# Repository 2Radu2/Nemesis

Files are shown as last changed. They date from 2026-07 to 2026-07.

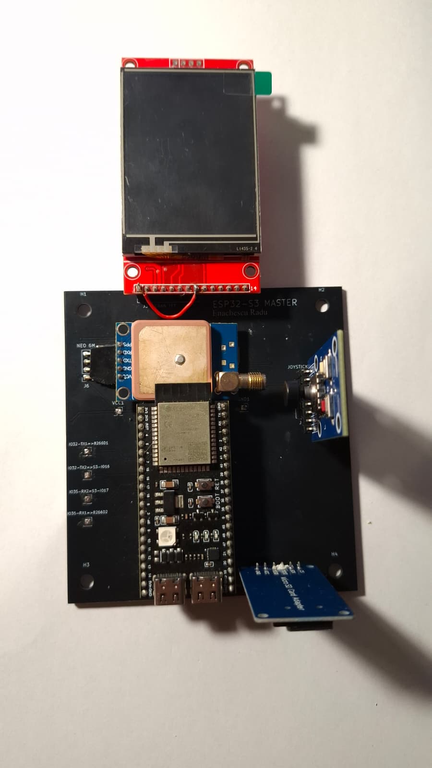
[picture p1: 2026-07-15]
Images/PCB populated & unpopulated/esp32 master pop.jpeg

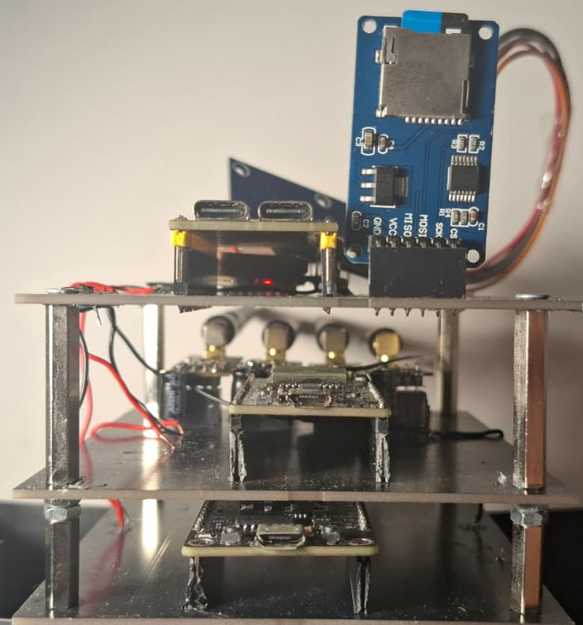
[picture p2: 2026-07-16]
Images/Final Stack/back view.jpeg

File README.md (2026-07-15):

# Project Nemesis: Modular Wireless Auditor

## Legal Disclaimer
**This project is for educational and academic research purposes only.**

Project Nemesis was developed as a university thesis project to audit, stress-test, and evaluate the resilience of modern wireless protocols (IEEE 802.11 and Bluetooth) in strictly controlled and isolated laboratory environments.

The author does not endorse, encourage, or take responsibility for any illegal, malicious, or unauthorized use of this hardware or software. Transmitting jamming signals or executing deauthentication attacks against networks or devices without explicit, written permission from the network owner is a federal crime in many jurisdictions (including under FCC regulations in the United States and similar laws worldwide).

By downloading, viewing, or building this project, you agree that you are solely responsible for your own actions and that you will comply with all local, state, and federal laws.

---

##  Overview
Project Nemesis is a portable, offensive security embedded system designed to audit and stress-test the resilience of modern wireless networks (Wi-Fi & Bluetooth).

Unlike standard auditing tools that rely on a single microcontroller (which often leads to severe UI lag and firmware bottlenecks during heavy RF injection), this project utilizes a custom **3-Stack Hardware Architecture**:
- **Layer 1 (Master Controller):** An ESP32-S3 handling the TFT UI, joystick navigation, and SD-Card GPS logging, completely isolated from RF tasks to ensure zero UI lag.
- **Layer 2 (Bluetooth Disruption):** An ESP32-32U paired with a Quad-nRF24L01+PA+LNA array. It executes protocol-level BLE advertising floods and brute-force AFH (Adaptive Frequency Hopping) poisoning across 79 channels.
- **Layer 3 (Wi-Fi Attacker):** An ESP8266 utilizing the raw Espressif SDK to execute 802.11 deauthentication and beacon spam attacks.

By synchronizing these independent layers, the system can execute "Combo Max"—a simultaneous, multi-vector attack capable of completely saturating the 2.4 GHz spectrum while maintaining a perfectly fluid user interface.

##  Hardware Components
This project relies on a custom 3-stack PCB architecture to distribute processing power and prevent UI bottlenecks. Below is the full bill of materials (BOM):

### Layer 1: Master Controller & UI
*   **Microcontroller:** ESP32-S3 (Dev Module)
*   **Display:** SPI TFT LCD Screen (e.g., ILI9341)
*   **Input:** 5-Pin Analog/Digital Joystick Module
*   **Telemetry:** GPS Module (u-blox NEO-6M / 7M)
*   **Storage:** MicroSD Card Adapter (SPI) + MicroSD Card

### Layer 2: Bluetooth Jammer
*   **Microcontroller:** ESP32-WROOM-32U (with U.FL connector for external BLE antenna)
*   **RF Array:** 4x nRF24L01+PA+LNA Transceiver Modules
*   **Antennas:** 5x 2.4GHz SMA Antennas (4 for NRF modules, 1 for ESP32 BLE)
*   **Power Smoothing:** 4x 10µF - 100µF Capacitors (essential for NRF module power stability)

### Layer 3: Wi-Fi Attacker
*   **Microcontroller:** ESP8266 (NodeMCU / Wemos D1 Mini)

### Power Delivery & PCB
*   **Battery:** 2500mAh Li-Po Battery (must support high current discharge ~1A+)
*   **Power Regulation:** High-current 3.3V and 5V Voltage Regulators
*   **Custom PCBs:** 3x Custom-designed Gerber boards (included in the /Hardware folder)

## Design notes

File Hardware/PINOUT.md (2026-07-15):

# Nemesis Hardware Pinout & Wiring Guide

This document provides the final, corrected pin mappings for the 3-stack PCB architecture, exactly as defined in the official thesis documentation. Use this as the definitive guide when wiring breadboards or soldering the PCBs.

---

## 1. ESP32-S3 (Master Controller)
*The central orchestrator and UI hub.*

### TFT LCD Display (SPI)
| Pin | ESP32-S3 GPIO |
| :--- | :--- |
| **MOSI** | `GPIO 11` |
| **SCK** | `GPIO 12` |
| **CS** | `GPIO 10` |
| **RST** | `GPIO 21` |
| **DC** | `GPIO 14` |
| **BL** (Backlight) | `GPIO 15` |

### MicroSD Card Adapter (SPI)
| Pin | ESP32-S3 GPIO |
| :--- | :--- |
| **MOSI** | `GPIO 39` |
| **MISO** | `GPIO 40` |
| **SCK** | `GPIO 38` |
| **CS** | `GPIO 41` |

### Peripheral Inputs
| Component | ESP32-S3 GPIO |
| :--- | :--- |
| **GPS Module (NEO-6M) RX** | `GPIO 18` |
| **Joystick UP** | `GPIO 1` |
| **Joystick DOWN** | `GPIO 2` |
| **Joystick LEFT** | `GPIO 4` |
| **Joystick RIGHT** | `GPIO 5` |
| **Joystick CENTER** | `GPIO 6` |

### Serial Comms to Slaves (UART)
| Slave | S3 TX Pin | S3 RX Pin |
| :--- | :--- | :--- |
| **To ESP32-32U (Bluetooth)** | `GPIO 17` | `GPIO 16` |
| **To ESP8266 (Wi-Fi)** | `GPIO 7` | `GPIO 8` |

---

## 2. ESP32-WROOM-32U (Bluetooth Jammer)
*The dedicated slave handling the quad-nRF array and BLE floods.*

### Serial Comms to Master
| Pin | ESP32-32U GPIO | Connects To |
| :--- | :--- | :--- |
| **RX** | `GPIO 35` | S3 TX (`GPIO 17`) |
| **TX** | `GPIO 32` | S3 RX (`GPIO 16`) |

### Shared SPI Buses for NRF Modules
To prevent data collisions during high-speed AFH poisoning, the 4 radios are split across two separate hardware SPI buses.

| Bus | Radios | MOSI | MISO | SCK |
| :--- | :--- | :--- | :--- | :--- |
| **HSPI** | NRF 1 & 2 | `13` | `12` | `14` |
| **VSPI** | NRF 3 & 4 | `23` | `19` | `18` |

### NRF Individual Control Pins (CE & CSN)
| Module | CE Pin | CSN Pin |
| :--- | :--- | :--- |
| **NRF 1** | `GPIO 16` | `GPIO 15` |
| **NRF 2** | `GPIO 17` | `GPIO 4` |
| **NRF 3** | `GPIO 25` | `GPIO 26` |
| **NRF 4** | `GPIO 22` | `GPIO 21` |

---

## 3. ESP8266 (Wi-Fi Attacker)
*The dedicated Wi-Fi Deauthentication and Beacon Flood coprocessor.*

### Serial Comms to Master
| Pin | ESP8266 Pin | Connects To |
| :--- | :--- | :--- |
| **RX** | `D1 (GPIO 5)` | S3 TX (`GPIO 7`) |
| **TX** | `D2 (GPIO 4)` | S3 RX (`GPIO 8`) |

> [!IMPORTANT]
> **UART Crossover Rule:** When connecting the master to the slaves, you must cross the lines. The **TX** on the Master goes to the **RX** on the slave, and vice-versa.

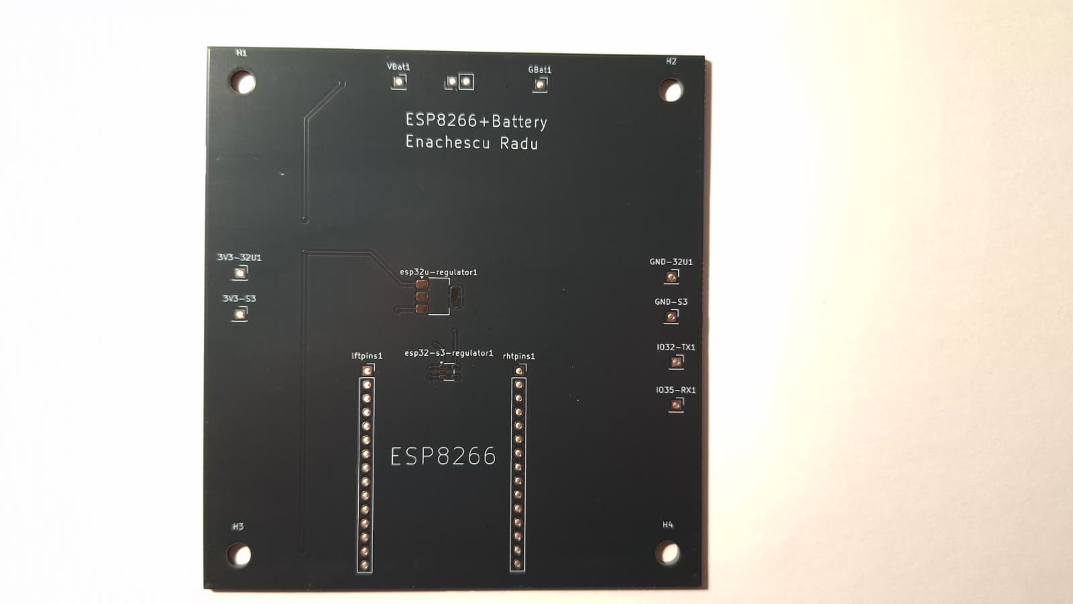
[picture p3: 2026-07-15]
Images/PCB populated & unpopulated/esp8266 unpop.jpeg

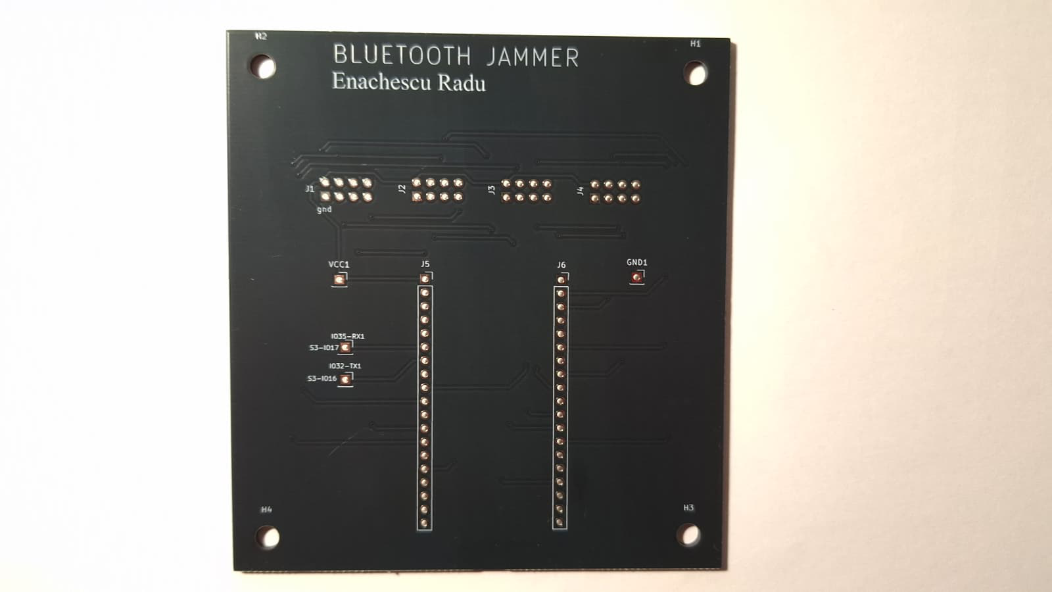
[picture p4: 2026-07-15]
Images/PCB populated & unpopulated/bt jammer unpop.jpeg

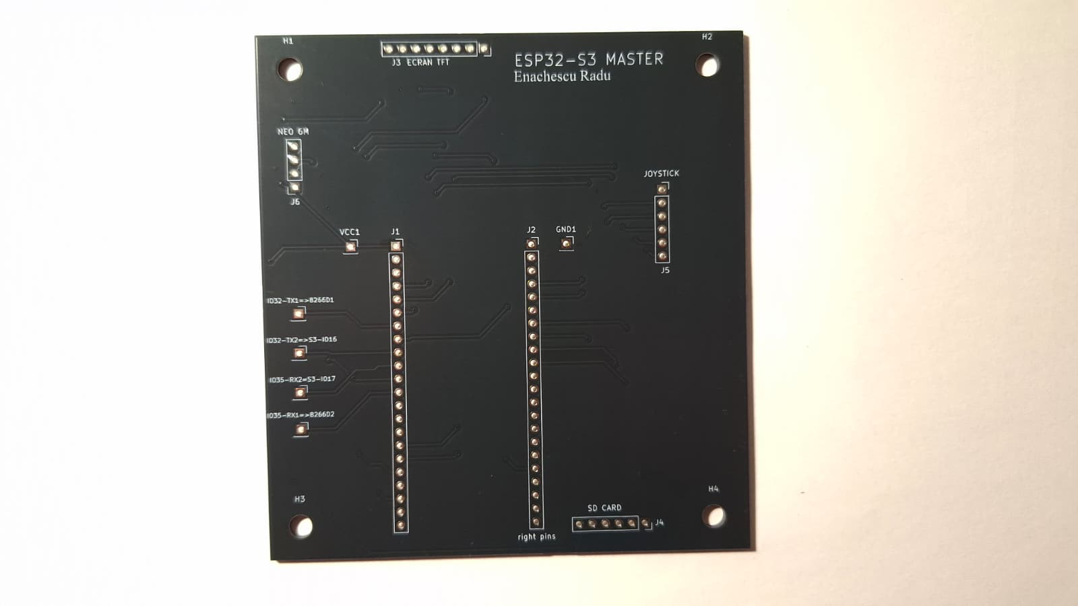
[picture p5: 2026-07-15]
Images/PCB populated & unpopulated/esp32 master unpop.jpeg

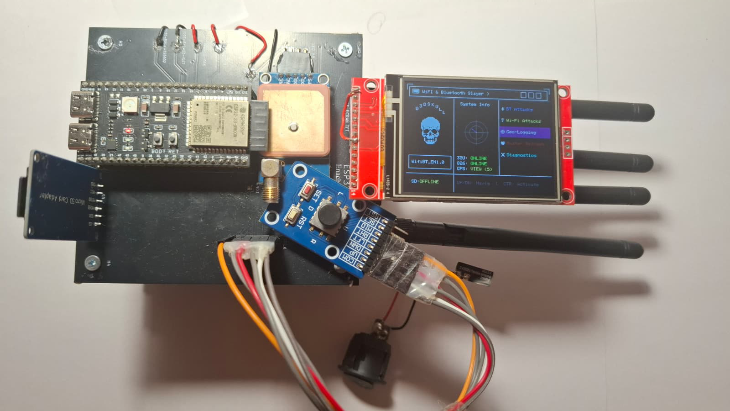
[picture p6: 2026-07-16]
Images/Final Stack/top view.jpeg

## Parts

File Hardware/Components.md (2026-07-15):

##  Hardware Components

This project relies on a custom 3-stack PCB architecture to distribute processing power and prevent UI bottlenecks. Below is the full bill of materials (BOM):

### Layer 1: Master Controller & UI
*   **Microcontroller:** ESP32-S3 (Dev Module)
*   **Display:** SPI TFT LCD Screen (e.g., ILI9341)
*   **Input:** 5-Pin Analog/Digital Joystick Module
*   **Telemetry:** GPS Module (u-blox NEO-6M / 7M)
*   **Storage:** MicroSD Card Adapter (SPI) + MicroSD Card

### Layer 2: Bluetooth Jammer
*   **Microcontroller:** ESP32-WROOM-32U (with U.FL connector for external BLE antenna)
*   **RF Array:** 4x nRF24L01+PA+LNA Transceiver Modules
*   **Antennas:** 4x 2.4GHz SMA Antennas + 1x 2.4Ghz U.FL (4 for NRF modules, 1 for ESP32 BLE)
*   **Power Smoothing:** 4x 10µF - 100µF Capacitors (essential for NRF module power stability, connected on the VCC& GND of the nRF24L01)

### Layer 3: Wi-Fi Attacker
*   **Microcontroller:** ESP8266 (NodeMCU / Wemos D1 Mini)

### Power Delivery & PCB
*   **Battery:** 2500mAh Li-Po Battery (must support high current discharge ~1A+)
*   **Power Regulation:** High-current 3.3V and 5V Voltage Regulators (LDOs/Buck converters capable of handling >1A peaks)
*   **Custom PCBs:** 3x Custom-designed Gerber boards (included in the `/Hardware` folder)
*   **Connectors:** 2.54mm Pitch Male/Female Headers for stacking

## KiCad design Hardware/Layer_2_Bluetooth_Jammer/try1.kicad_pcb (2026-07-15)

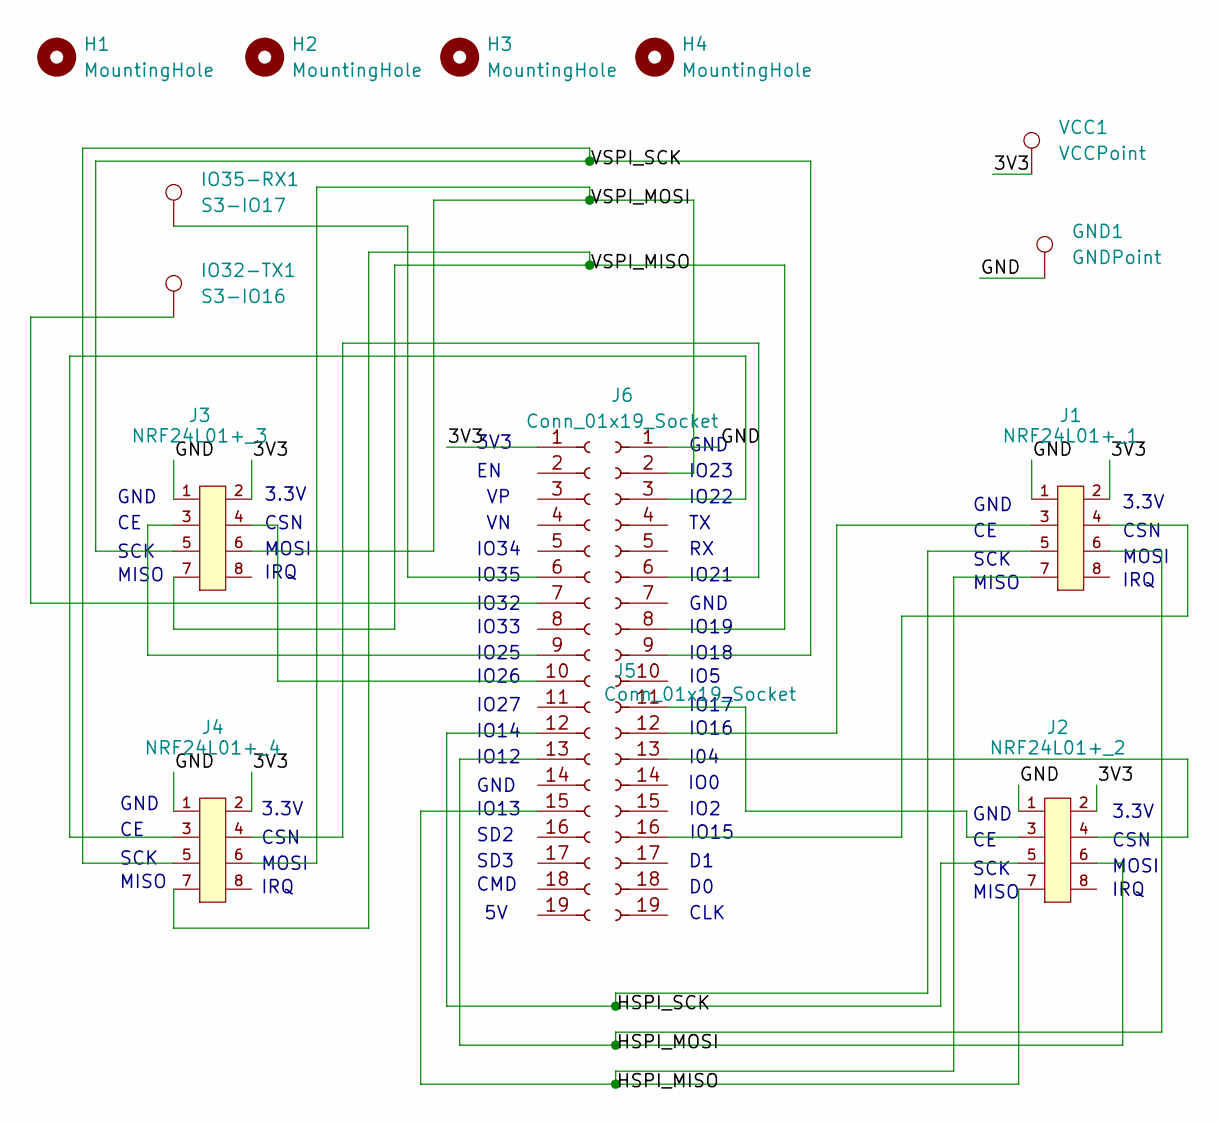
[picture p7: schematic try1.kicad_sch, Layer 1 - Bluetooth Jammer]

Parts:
GND1: GNDPoint; PinSocket_1x01_P2.54mm_Vertical
H1, H2, H3, H4: MountingHole; MountingHole_4.3mm_M4
IO32-TX1: S3-IO16; PinSocket_1x01_P2.54mm_Vertical
IO35-RX1: S3-IO17; PinSocket_1x01_P2.54mm_Vertical
J1: NRF24L01+_1; PinSocket_2x04_P2.54mm_Vertical
J2: NRF24L01+_2; PinSocket_2x04_P2.54mm_Vertical
J3: NRF24L01+_3; PinSocket_2x04_P2.54mm_Vertical
J4: NRF24L01+_4; PinSocket_2x04_P2.54mm_Vertical
J5, J6: Conn_01x19_Socket; PinSocket_1x19_P2.54mm_Vertical
VCC1: VCCPoint; PinSocket_1x01_P2.54mm_Vertical

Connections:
/3V3: J1.2 (VCC), J2.2 (VCC), J3.2 (VCC), J4.2 (VCC), J5.1, VCC1.1 (1_1)
/GND: GND1.1 (1_1), J1.1 (GND), J2.1 (GND), J3.1 (GND), J4.1 (GND), J6.1
/HSPI_MISO: J1.7 (MISO), J2.7 (MISO), J5.15
/HSPI_MOSI: J1.6 (MOSI), J2.6 (MOSI), J5.13
/HSPI_SCK: J1.5 (SCK), J2.5 (SCK), J5.12
/VSPI_MISO: J3.7 (MISO), J4.7 (MISO), J6.8
/VSPI_MOSI: J3.6 (MOSI), J4.6 (MOSI), J6.2
/VSPI_SCK: J3.5 (SCK), J4.5 (SCK), J6.9
unnamed: J1.3 (CE), J6.12
unnamed: J1.4 (CSN), J6.16
unnamed: J2.3 (CE), J6.11
unnamed: J2.4 (CSN), J6.13
unnamed: J3.3 (CE), J5.9
unnamed: J3.4 (CSN), J5.10
unnamed: J4.3 (CE), J6.3
unnamed: J4.4 (CSN), J6.6
unnamed: IO35-RX1.1 (1_1), J5.6
unnamed: IO32-TX1.1 (1_1), J5.7

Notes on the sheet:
MOSI
IO21
IO27
SCK
IO19
3.3V
IO14
SD3
I04
IO17
GND
IO2
3V3
IO23
IO16
CSN
MISO
GND
IO0
CLK
CMD
IO18
IO32
IO5
IO15
IO34
IO12
IO13
IRQ
IO35
IO33
IO26
IO22
IO25
SD2

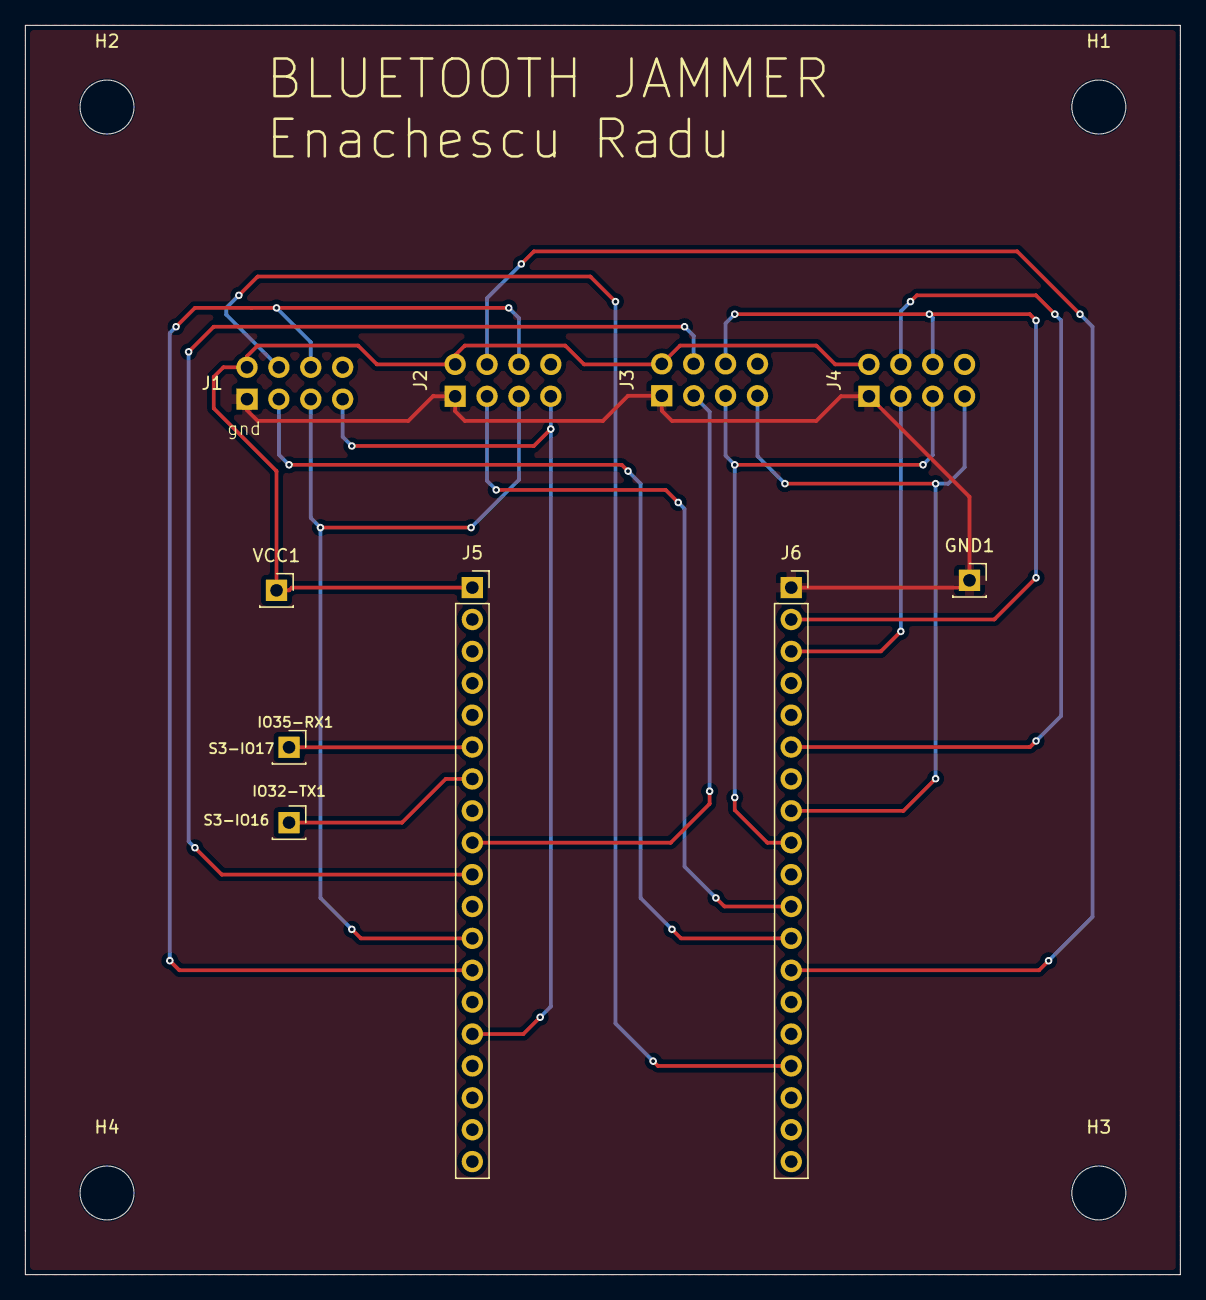
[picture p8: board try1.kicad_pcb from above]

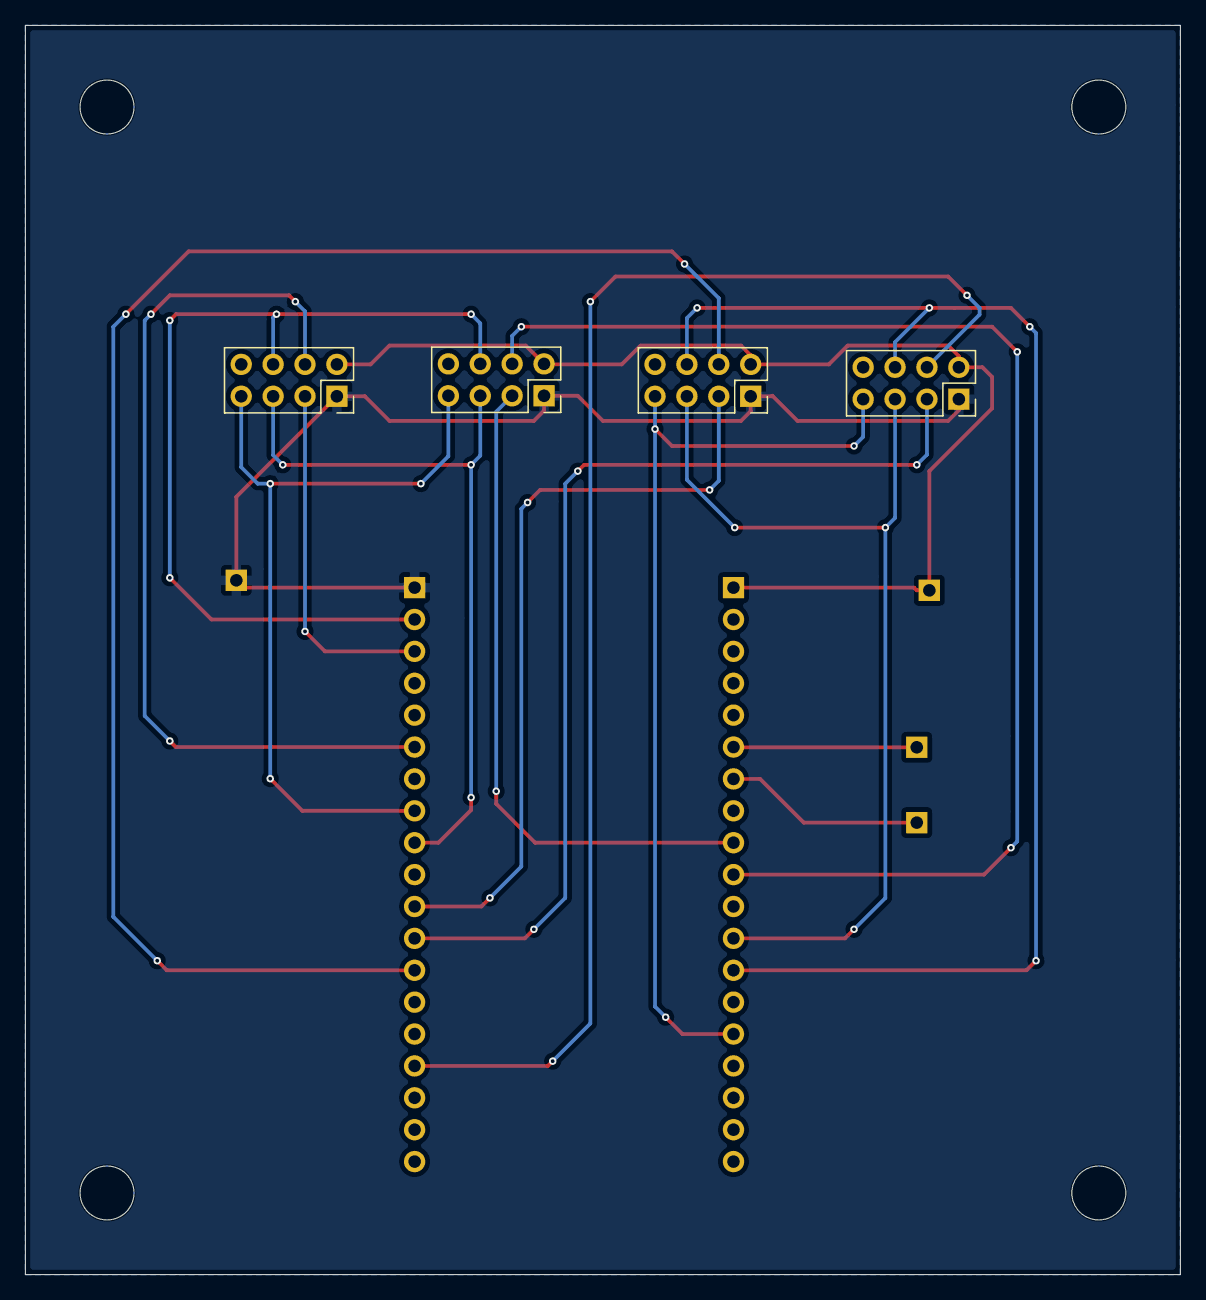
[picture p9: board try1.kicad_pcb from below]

Board: 2 copper layers, 92.0 x 99.5 mm, 14 parts (4 on the bottom side), 18 nets.

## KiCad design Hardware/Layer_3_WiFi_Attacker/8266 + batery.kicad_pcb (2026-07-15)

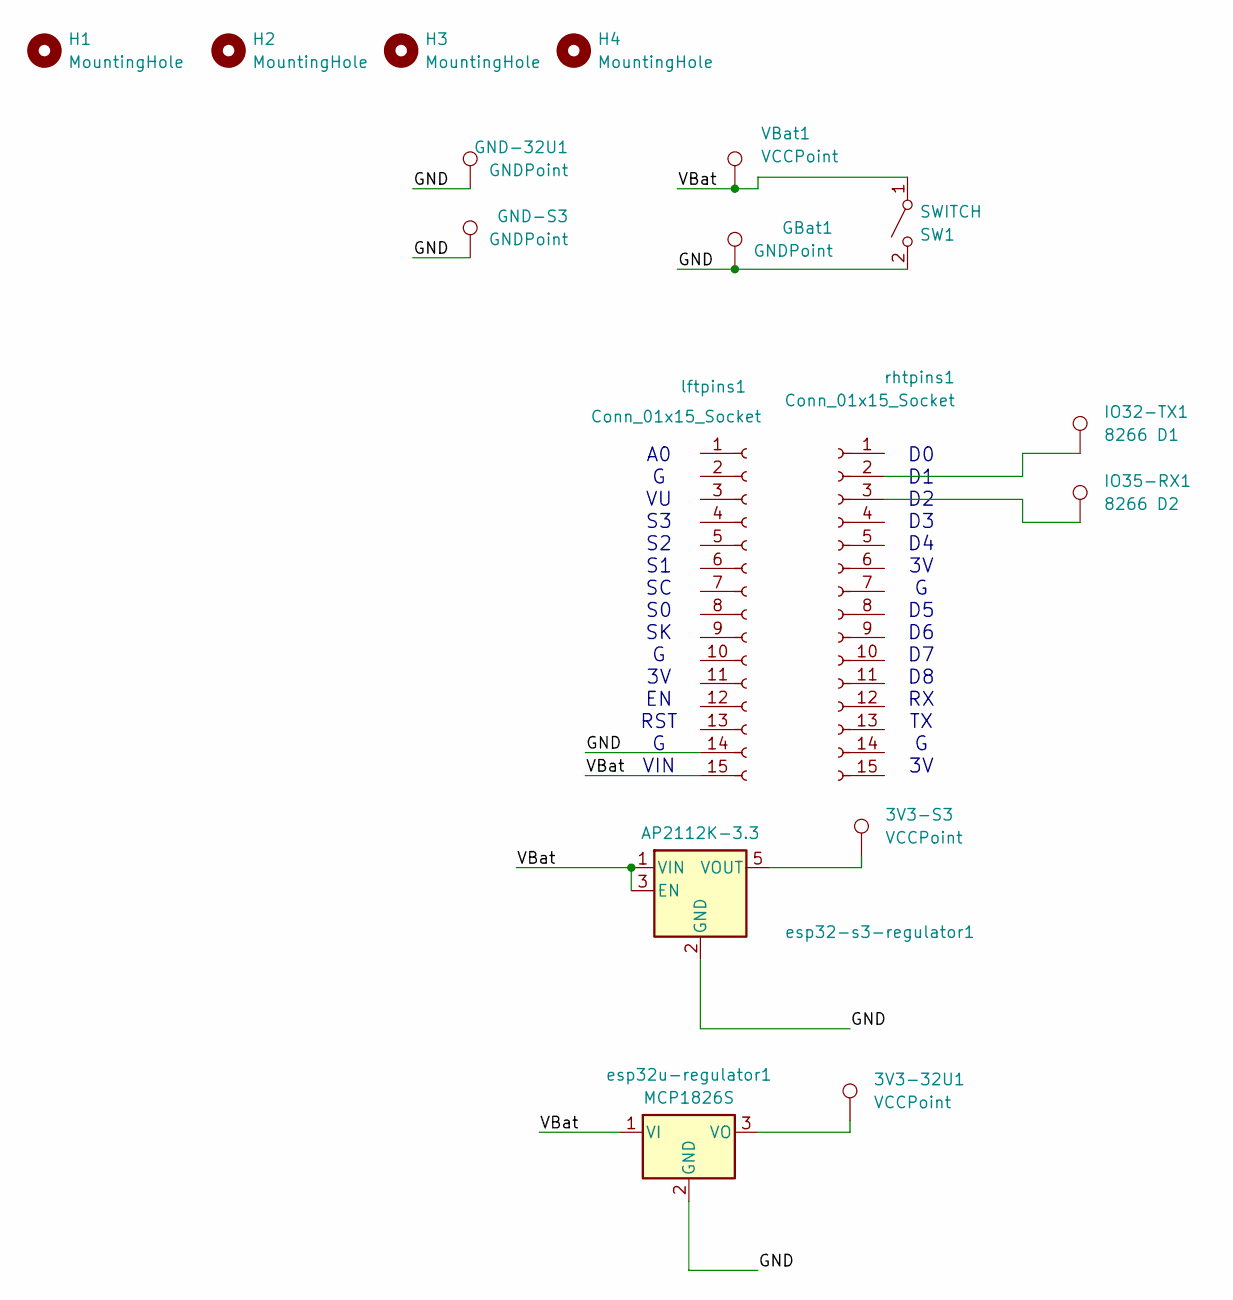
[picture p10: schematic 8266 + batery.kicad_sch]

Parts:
3V3-32U1, 3V3-S3: VCCPoint; PinSocket_1x01_P2.54mm_Vertical
GBat1: GNDPoint; PinSocket_1x01_P2.54mm_Vertical
GND-32U1: GNDPoint; PinSocket_1x01_P2.54mm_Vertical
GND-S3: GNDPoint; PinSocket_1x01_P2.54mm_Vertical
H1, H2, H3, H4: MountingHole; MountingHole_4.3mm_M4
IO32-TX1: 8266 D1; PinSocket_1x01_P2.54mm_Vertical
IO35-RX1: 8266 D2; PinSocket_1x01_P2.54mm_Vertical
SW1: SWITCH; PinHeader_1x02_P2.54mm_Vertical
VBat1: VCCPoint; PinSocket_1x01_P2.54mm_Vertical
esp32-s3-regulator1: AP2112K-3.3; SOT-23-5
esp32u-regulator1: MCP1826S; SOT-223-3_TabPin2
lftpins1: Conn_01x15_Socket; PinSocket_1x15_P2.54mm_Vertical
rhtpins1: Conn_01x15_Socket; PinSocket_1x15_P2.54mm_Vertical

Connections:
/GND: GBat1.1 (1_1), GND-32U1.1 (1_1), GND-S3.1 (1_1), SW1.2 (B), esp32-s3-regulator1.2 (GND), esp32u-regulator1.2 (GND), lftpins1.14
/VBat: SW1.1 (A), VBat1.1 (1_1), esp32-s3-regulator1.1 (VIN), esp32-s3-regulator1.3 (EN), esp32u-regulator1.1 (VI), lftpins1.15
unnamed: 3V3-S3.1 (1_1), esp32-s3-regulator1.5 (VOUT)
unnamed: 3V3-32U1.1 (1_1), esp32u-regulator1.3 (VO)
unnamed: IO32-TX1.1 (1_1), rhtpins1.2
unnamed: IO35-RX1.1 (1_1), rhtpins1.3

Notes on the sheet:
A0 G VU S3 S2 S1 SC S0 SK G 3V EN RST G VIN
D0 D1 D2 D3 D4 3V G D5 D6 D7 D8 RX TX G 3V

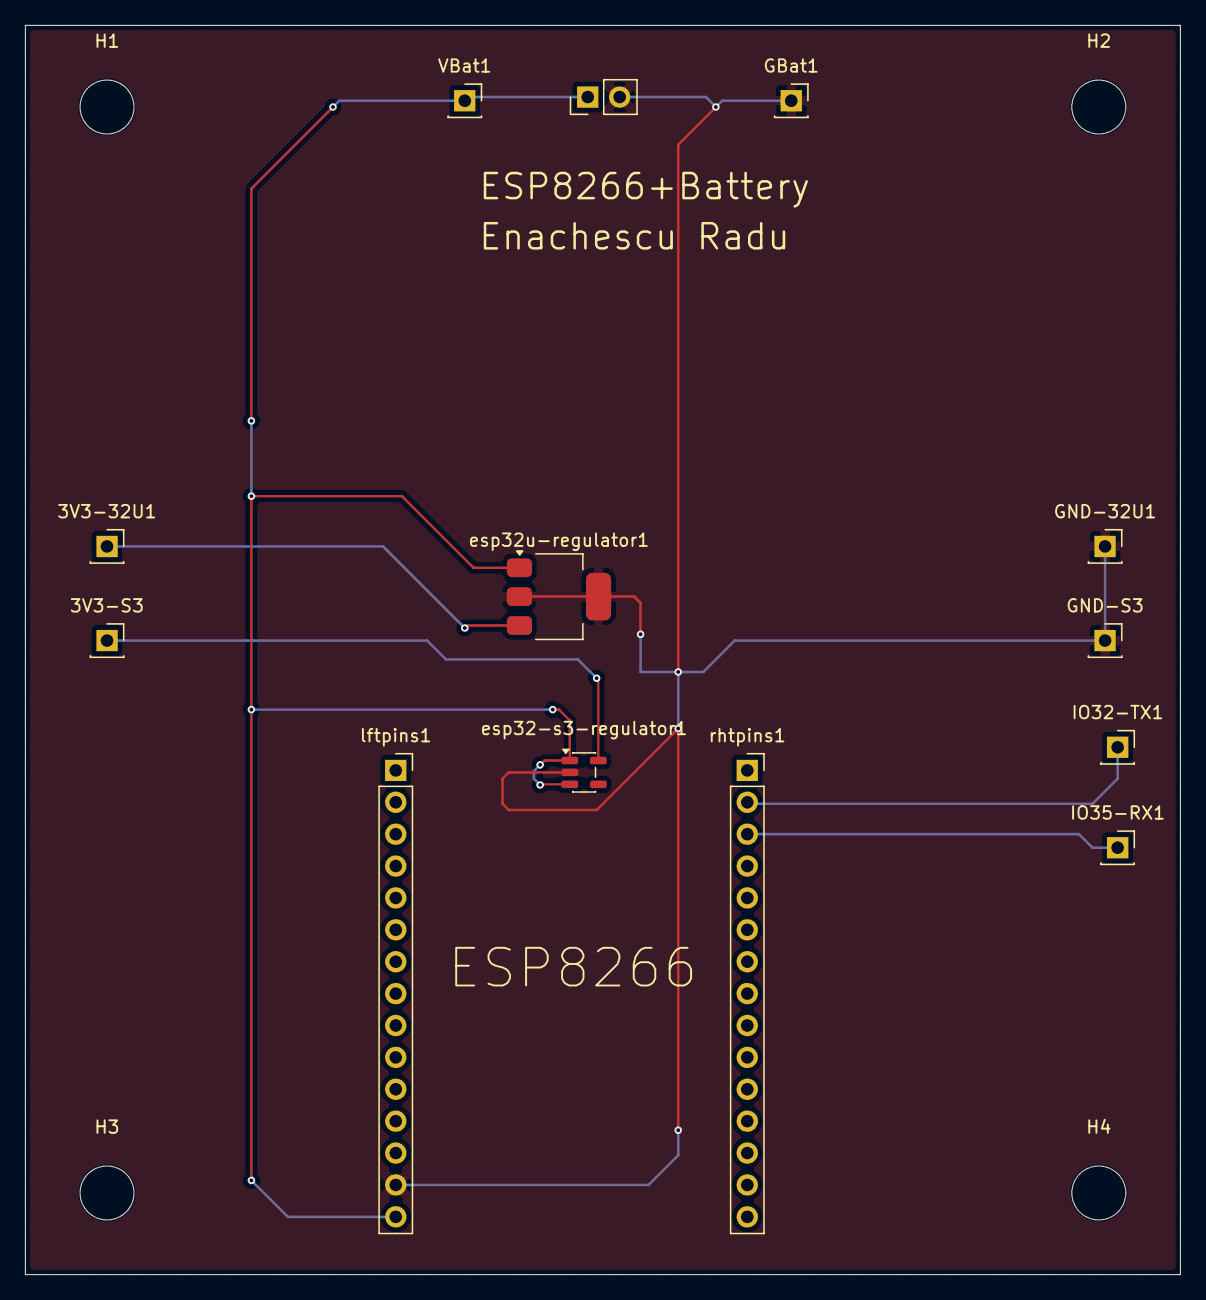
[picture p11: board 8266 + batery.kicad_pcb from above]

Board: 2 copper layers, 92.0 x 99.5 mm, 17 parts (0 on the bottom side), 6 nets.

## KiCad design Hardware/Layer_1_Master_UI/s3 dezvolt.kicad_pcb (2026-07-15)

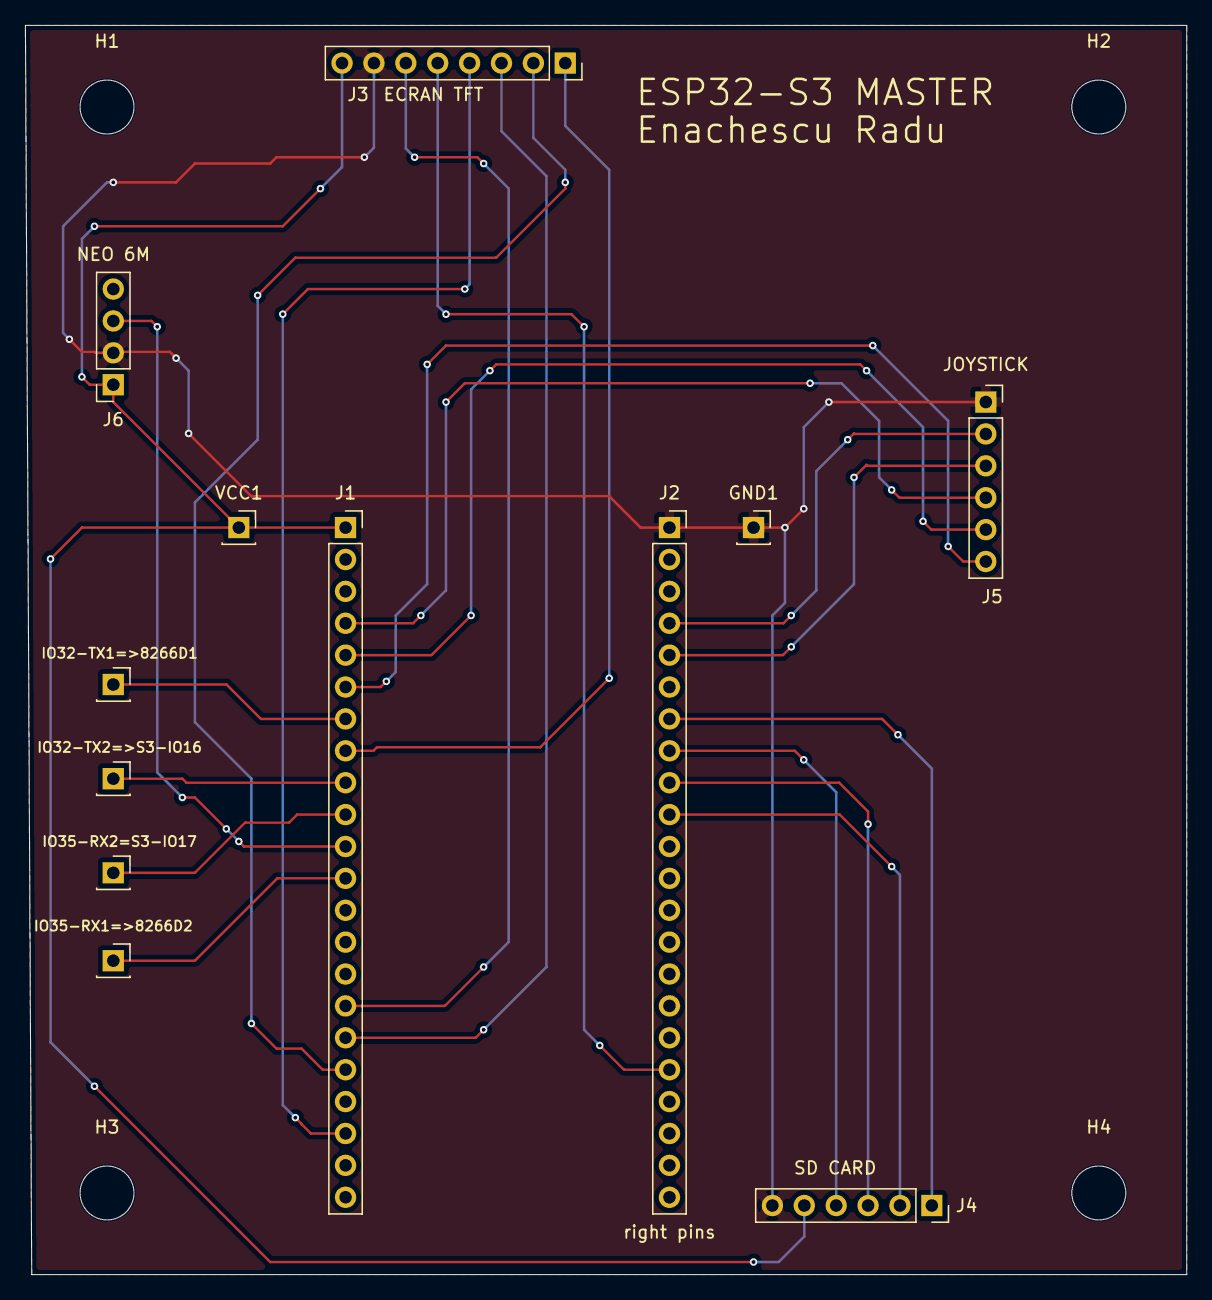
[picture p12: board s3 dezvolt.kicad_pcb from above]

Board: 2 copper layers, 92.5 x 99.5 mm, 16 parts (0 on the bottom side), 22 nets.

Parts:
GND1: GNDPoint; PinSocket_1x01_P2.54mm_Vertical
H1, H2, H3, H4: MountingHole; MountingHole_4.3mm_M4
IO32-TX1=>8266D1: 8266 D1; PinSocket_1x01_P2.54mm_Vertical
IO32-TX2=>S3-IO16: S3-IO16; PinSocket_1x01_P2.54mm_Vertical
IO35-RX1=>8266D2: 8266 D2; PinSocket_1x01_P2.54mm_Vertical
IO35-RX2=S3-IO17: S3-IO17; PinSocket_1x01_P2.54mm_Vertical
J1: left pins; PinSocket_1x22_P2.54mm_Vertical
J2: right pins; PinSocket_1x22_P2.54mm_Vertical
J3: ECRAN TFT; PinSocket_1x08_P2.54mm_Vertical
J4: SD CARD; PinSocket_1x06_P2.54mm_Vertical
J5: JOYSTICK; PinSocket_1x06_P2.54mm_Vertical
J6: NEO 6M; PinSocket_1x04_P2.54mm_Vertical
VCC1: VCCPoint; PinSocket_1x01_P2.54mm_Vertical

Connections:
/3V3: J1.1, J3.8, J4.5, J6.1, VCC1.1 (1_1)
/GND: GND1.1 (1_1), J2.1, J3.7, J4.6, J5.1, J6.2
unnamed: J1.4, J5.4
unnamed: J1.5, J5.5
unnamed: J1.6, J5.6
unnamed: IO32-TX1=>8266D1.1 (1_1), J1.7
unnamed: J1.8, J3.1
unnamed: IO32-TX2=>S3-IO16.1 (1_1), J1.9
unnamed: IO35-RX2=S3-IO17.1 (1_1), J1.10
unnamed: J1.11, J6.3
unnamed: IO35-RX1=>8266D2.1 (1_1), J1.12
unnamed: J1.16, J3.6
unnamed: J1.17, J3.3
unnamed: J1.18, J3.2
unnamed: J1.20, J3.4
unnamed: J2.4, J5.2
unnamed: J2.5, J5.3
unnamed: J2.7, J4.1
unnamed: J2.8, J4.4
unnamed: J2.9, J4.3
unnamed: J2.10, J4.2
unnamed: J2.18, J3.5

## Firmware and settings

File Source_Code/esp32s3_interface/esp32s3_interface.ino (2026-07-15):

// ESP32-S3 Master UI Dashboard (ILI9341/ST7789)
#include <SPI.h>
#include <Adafruit_GFX.h>
#include <SD.h>
#include <TinyGPSPlus.h>
#include <SoftwareSerial.h>

// Disp Cfg:
#define USE_ILI9341    0   // ILI9341 
#define USE_ST7789     1   // ST7789
#define INVERT_COLORS  0   // Inv Col

#if USE_ILI9341
  #include <Adafruit_ILI9341.h>
#else
  #include <Adafruit_ST7789.h>
#endif

// Pins
#define TFT_CS 10
#define TFT_RST 21
#define TFT_DC 14
#define TFT_MOSI 11
#define TFT_SCK 12
#define TFT_BL 15
#define SD_SCK 38
#define SD_MOSI 39
#define SD_MISO 40
#define SD_CS 41
#define GPS_RX 18
#define JOY_UP 1
#define JOY_DOWN 2
#define JOY_LEFT 4
#define JOY_RIGHT 5
#define JOY_CENTER 6
#define UART32U_TX 17
#define UART32U_RX 16
#define ESP8266_TX 7
#define ESP8266_RX 8

// Objs
SPIClass spiSD(HSPI);
SPIClass tftSPI(FSPI);

#if USE_ILI9341
  Adafruit_ILI9341 tft = Adafruit_ILI9341(&tftSPI, TFT_DC, TFT_CS, TFT_RST);
#else
  Adafruit_ST7789 tft = Adafruit_ST7789(&tftSPI, TFT_CS, TFT_DC, TFT_RST);
#endif

TinyGPSPlus gps;
SoftwareSerial gpsSerial(GPS_RX, -1);
HardwareSerial uart32u(2);
HardwareSerial esp8266(1);

// UI Grid
#define COL1_X 0
#define COL1_W 104
#define COL2_X 104
#define COL2_W 100
#define COL3_X 204
#define COL3_W 116
#define HDR_H 30
#define BODY_Y 30
#define BODY_H 170
#define FTR_Y 200
#define FTR_H 40

// Colors
#define C_BG    0x0000  // Blk
#define C_WHITE 0xFFFF  // Wht
#define C_FRAME 0x4A49  // D-Gry
#define C_STAR  0x2945  // Stars

// Menu Colors
#define C_BLE   0x237D  // BLE (Purp)
#define C_WIFI  0xFF47  // WiFi (Org)
#define C_SCAN  0x14A1  // Scan (Grn)
#define C_EVIL  0xB882  // Evil (Red)
#define C_UTIL  0x07F7  // Util (Cyn)
#define C_SEL   0x780F  // Sel (Blk)

// Menu Items
int curSel = 0;
const int N_ITEMS = 5;
const char* mLabel[] = {"BLE Attacks", "Wi-Fi Attacks", "Scanning", "Evil-USB stuff", "Utils"};
const uint16_t mColor[] = {C_BLE, C_WIFI, C_SCAN, C_EVIL, C_UTIL};
bool sdOK = false;
bool joyU=false, joyD=false, joyC=false;

// Skull bmp
static const unsigned char PROGMEM image_paint_6_bits[] = {0x80};
static const unsigned char PROGMEM image_skull_bits[] = {0xff,0xff,0xff,0xff,0xff,0xff,0xff,0xff,0xff,0xff,0xff,0xff,0xff,0xff,0xff,0xff,0xff,0xff,0xff,0xff,0xff,0xff,0xff,0xff,0xff,0xff,0xff,0xff,0xff,0xff,0xff,0xff,0xff,0xff,0xff,0xff,0xff,0xff,0xff,0xff,0xff,0xf0,0x00,0x00,0x00,0x00,0x00,0x00,0x0f,0xff,0xff,0xf0,0x00,0x00,0x00,0x00,0x00,0x00,0x0f,0xff,0xff,0xf0,0x00,0x00,0x00,0x00,0x00,0x00,0x0f,0xff,0xff,0xf0,0x00,0x00,0x00,0x00,0x00,0x00,0x0f,0xff,0xff,0xf0,0x00,0x00,0x00,0x00,0x00,0x00,0x0f,0xff,0xff,0xf0,0x00,0x00,0x3f,0xfe,0x00,0x00,0x0f,0xff,0xff,0xf0,0x00,0x00,0x3f,0xfe,0x00,0x00,0x0f,0xff,0xff,0xf0,0x00,0x01,0xff,0xff,0xc0,0x00,0x0f,0xff,0xff,0xf0,0x00,0x01,0xff,0xff,0xc0,0x00,0x0f,0xff,0xff,0xf0,0x00,0x1f,0xff,0xff,0xfc,0x00,0x0f,0xff,0xff,0xf0,0x00,0x1f,0xff,0xff,0xfc,0x00,0x0f,0xff,0xff,0xf0,0x00,0x7f,0xff,0xff,0xff,0x00,0x0f,0xff,0xff,0xf0,0x01,0xff,0xff,0xff,0xff,0x80,0x0f,0xff,0xff,0xf0,0x01,0xff,0xff,0xff,0xff,0x80,0x0f,0xff,0xff,0xf0,0x03,0xff,0xff,0xff,0xff,0xe0,0x0f,0xff,0xff,0xf0,0x03,0xff,0xff,0xff,0xff,0xe0,0x0f,0xff,0xff,0xf0,0x03,0xff,0xff,0xff,0xff,0xe0,0x0f,0xff,0xff,0xf0,0x03,0xff,0xff,0xff,0xff,0xe0,0x0f,0xff,0xff,0xf0,0x0f,0xff,0xff,0xff,0xff,0xf8,0x0f,0xff,0xff,0xf0,0x0f,0xff,0xff,0xff,0xff,0xf8,0x0f,0xff,0xff,0xf0,0x0f,0xff,0xff,0xff,0xff,0xf8,0x0f,0xff,0xff,0xf0,0x0f,0xff,0xff,0xff,0xff,0xf8,0x0f,0xff,0xff,0xf0,0x0f,0xff,0xff,0xff,0xff,0xf8,0x0f,0xff,0xff,0xf0,0x0f,0xff,0xff,0xff,0xff,0xf8,0x0f,0xff,0xff,0xf0,0x0f,0xff,0xff,0xff,0xff,0xf8,0x0f,0xff,0xff,0xf0,0x0e,0x7f,0xff,0xff,0xff,0x38,0x0f,0xff,0xff,0xf0,0x0e,0x7f,0xff,0xff,0xff,0x38,0x0f,0xff,0xff,0xf0,0x0e,0x7f,0x03,0xe0,0x7f,0x38,0x0f,0xff,0xff,0xf0,0x0f,0x9f,0xfc,0x9f,0xfc,0xf8,0x0f,0xff,0xff,0xf0,0x0f,0x9f,0xfc,0x9f,0xfc,0xf8,0x0f,0xff,0xff,0xf0,0x0f,0x9f,0xff,0xff,0xfc,0xf8,0x0f,0xff,0xff,0xf0,0x0f,0x9f,0xff,0xff,0xfc,0xf8,0x0f,0xff,0xff,0xf0,0x03,0x98,0x0e,0x78,0x0c,0xe0,0x0f,0xff,0xff,0xf0,0x03,0x98,0x0e,0x78,0x0c,0xe0,0x0f,0xff,0xff,0xf0,0x02,0x60,0x00,0x80,0x03,0x20,0x0f,0xff,0xff,0xf0,0x00,0x00,0x00,0x80,0x00,0x00,0x0f,0xff,0xff,0xf0,0x01,0x80,0x03,0xe0,0x00,0x80,0x0f,0xff,0xff,0xf0,0x01,0x80,0x03,0xe0,0x00,0x80,0x0f,0xff,0xff,0xf0,0x01,0x80,0x03,0xe0,0x00,0x80,0x0f,0xff,0xff,0xf0,0x03,0x80,0x0e,0x78,0x00,0xe0,0x0f,0xff,0xff,0xf0,0x03,0x80,0x0e,0x78,0x00,0xe0,0x0f,0xff,0xff,0xf0,0x03,0xe0,0x7c,0x1f,0x03,0xe0,0x0f,0xff,0xff,0xf0,0x03,0xe0,0x7c,0x1f,0x03,0xe0,0x0f,0xff,0xff,0xf0,0x03,0x9f,0x0c,0x18,0x7c,0xe0,0x0f,0xff,0xff,0xf0,0x03,0x80,0x0c,0x18,0x00,0xe0,0x0f,0xff,0xff,0xf0,0x03,0xe0,0x7c,0x1f,0x03,0xe0,0x0f,0xff,0xff,0xf0,0x01,0xfe,0x7c,0x9f,0x3f,0x80,0x0f,0xff,0xff,0xf0,0x01,0xfe,0x7c,0x9f,0x3f,0x80,0x0f,0xff,0xff,0xf0,0x00,0x79,0xff,0xff,0xcf,0x00,0x0f,0xff,0xff,0xf0,0x00,0x79,0xff,0xff,0xcf,0x00,0x0f,0xff,0xff,0xf0,0x00,0x00,0x7f,0xff,0x00,0x00,0x0f,0xff,0xff,0xf0,0x00,0x00,0x7f,0xff,0x00,0x00,0x0f,0xff,0xff,0xf0,0x00,0x18,0x4e,0x79,0x0c,0x00,0x0f,0xff,0xff,0xf0,0x00,0x18,0x4e,0x79,0x0c,0x00,0x0f,0xff,0xff,0xf0,0x00,0x18,0x4e,0x79,0x0c,0x00,0x0f,0xff,0xff,0xf0,0x00,0x18,0x00,0x00,0x0c,0x00,0x0f,0xff,0xff,0xf0,0x00,0x18,0x00,0x00,0x0c,0x00,0x0f,0xff,0xff,0xf0,0x00,0x18,0x4e,0x79,0x0c,0x00,0x0f,0xff,0xff,0xf0,0x00,0x18,0x4e,0x79,0x0c,0x00,0x0f,0xff,0xff,0xf0,0x00,0x06,0x4e,0x79,0x30,0x00,0x0f,0xff,0xff,0xf0,0x00,0x04,0xce,0x79,0x30,0x00,0x0f,0xff,0xff,0xf0,0x00,0x01,0xff,0xff,0xc0,0x00,0x0f,0xff,0xff,0xf0,0x00,0x01,0xff,0xff,0xc0,0x00,0x0f,0xff,0xff,0xf0,0x00,0x01,0xff,0xff,0xc0,0x00,0x0f,0xff,0xff,0xf0,0x00,0x00,0x3f,0xfe,0x00,0x00,0x0f,0xff,0xff,0xf0,0x00,0x00,0x3f,0xfe,0x00,0x00,0x0f,0xff,0xff,0xf0,0x00,0x00,0x00,0x00,0x00,0x00,0x0f,0xff,0xff,0xf0,0x00,0x00,0x00,0x00,0x00,0x00,0x0f,0xff,0xff,0xf0,0x00,0x00,0x00,0x00,0x00,0x00,0x0f,0xff,0xff,0xf0,0x00,0x00,0x00,0x00,0x00,0x00,0x0f,0xff,0xff,0xf0,0x00,0x00,0x00,0x00,0x00,0x00,0x0f,0xff,0xff,0xf0,0x00,0x00,0x00,0x00,0x00,0x00,0x0f,0xff,0xff,0xff,0xff,0xff,0xff,0xff,0xff,0xff,0xff,0xff,0xff,0xff,0xff,0xff,0xff,0xff,0xff,0xff,0xff,0xff,0xff,0xff,0xff,0xff,0xff,0xff,0xff,0xff,0xff,0xff};

// 8x8 Icons
const unsigned char ico_bt[] PROGMEM  = {0x08,0x0C,0x2A,0x1C,0x1C,0x2A,0x0C,0x08}; // BT
const unsigned char ico_wf[] PROGMEM  = {0x3C,0x42,0x18,0x24,0x00,0x18,0x18,0x00}; // WiFi
const unsigned char ico_sc[] PROGMEM  = {0x3C,0x42,0x99,0xA5,0xA5,0x99,0x42,0x3C}; // Scan
const unsigned char ico_hw[] PROGMEM  = {0x42,0x7E,0xDB,0xFF,0xBD,0x7E,0x3C,0x24}; // HW
const unsigned char ico_ge[] PROGMEM  = {0xC3,0x66,0x3C,0x18,0x18,0x3C,0x66,0xC3}; // Gear
const unsigned char* mIcon[] = {ico_bt, ico_wf, ico_sc, ico_hw, ico_ge};

// Batt bmp
const unsigned char ico_batt[] PROGMEM = {
  0xFF,0xFC, 0x80,0x06, 0xBF,0xF6, 0xBF,0xF6, 0xBF,0xF6,
  0xBF,0xF6, 0xBF,0xF6, 0xBF,0xF6, 0x80,0x06, 0xFF,0xFC
};

// Stars
void drawStars(int x0, int y0, int w, int h) {
  for (int i = 0; i < 15; i++) {
    int sx = x0 + ((i * 37 + 13) % w);
    int sy = y0 + ((i * 53 + 7) % h);
    if (sx > x0+1 && sx < x0+w-2 && sy > y0+1 && sy < y0+h-2) {
      tft.drawPixel(sx, sy, C_STAR);
      tft.drawPixel(sx-1, sy, C_STAR);
      tft.drawPixel(sx+1, sy, C_STAR);
      tft.drawPixel(sx, sy-1, C_STAR);
      tft.drawPixel(sx, sy+1, C_STAR);
    }
  }
}

// Corners
void drawCorners(int x, int y, int w, int h, int sz, uint16_t col) {
  // TL
  tft.drawLine(x, y, x+sz, y, col);
  tft.drawLine(x, y, x, y+sz, col);
  // TR
  tft.drawLine(x+w-1-sz, y, x+w-1, y, col);
  tft.drawLine(x+w-1, y, x+w-1, y+sz, col);
  // BL
  tft.drawLine(x, y+h-1, x+sz, y+h-1, col);
  tft.drawLine(x, y+h-1-sz, x, y+h-1, col);
  // BR
  tft.drawLine(x+w-1-sz, y+h-1, x+w-1, y+h-1, col);
  tft.drawLine(x+w-1, y+h-1-sz, x+w-1, y+h-1, col);
}

// Header
void drawHeader() {
  // Brackets
  drawCorners(0, 0, 320, 240, 12, C_WHITE);
  
  // Box
  tft.drawRect(5, 5, 310, 23, C_WHITE);
  
  // Battery icon header
  tft.drawBitmap(12, 11, ico_batt, 16, 10, C_WHITE);
  
  // Title
  tft.setTextColor(C_WHITE);
  tft.setTextSize(1);
  tft.setCursor(34, 13);
  tft.print("WiFI & Bluetooth Slayer >");
  
  // Stat box
  for (int i = 0; i < 3; i++) {
    tft.drawRect(255 + i*17, 10, 12, 13, C_WHITE);
  }
  
  // Divider
  tft.drawLine(0, HDR_H-1, 319, HDR_H-1, C_FRAME);
}

// L-Pane
void drawLeftPane() {
  // Divider
  tft.drawLine(COL1_W, BODY_Y, COL1_W, FTR_Y-1, C_WHITE);
  
  // Stars
  drawStars(5, BODY_Y+5, COL1_W-10, BODY_H-10);
  
  // Skull
  int sx = (COL1_W - 80) / 2; 
  int sy = BODY_Y + 35;      
  tft.drawBitmap(sx, sy, image_skull_bits, 80, 80, C_WHITE);
  
  // Masking
  tft.fillRect(sx, sy + 76, 80, 4, C_BG);      
  tft.fillRect(sx + 68, sy, 12, 76, C_BG);     
  tft.fillRect(sx - 1, sy, 69, 4, C_BG);       
  tft.fillRect(sx, sy + 4, 12, 73, C_BG);      

 
  tft.setTextColor(C_WHITE);
  tft.setTextSize(1);
  tft.setCursor(20, BODY_Y + 22); tft.print("D");
  tft.setCursor(28, BODY_Y + 16); tft.print("3");
  tft.setCursor(37, BODY_Y + 12); tft.print("D");
  tft.setCursor(46, BODY_Y + 11); tft.print("S");
  tft.setCursor(55, BODY_Y + 12); tft.print("K");
  tft.setCursor(64, BODY_Y + 16); tft.print("U");
  tft.setCursor(72, BODY_Y + 22); tft.print("L");
  tft.setCursor(80, BODY_Y + 29); tft.print("L");
  
  // paint 6
  tft.drawBitmap(sx + 30, sy + 63, image_paint_6_bits, 1, 1, C_WHITE);
  
  // Bottom Box
  tft.drawRect(5, BODY_Y + 130, COL1_W - 10, 30, C_WHITE);
  tft.setTextColor(C_WHITE);
  tft.setTextSize(1);
  tft.setCursor(12, BODY_Y + 141);
  tft.print("WifiBT_EN1.0");
}

// M-Pane
void drawMiddlePane() {
  // Divider
  tft.drawLine(COL2_X + COL2_W, BODY_Y, COL2_X + COL2_W, FTR_Y-1, C_WHITE);
  
  // Stars
  drawStars(COL2_X+5, BODY_Y+5, COL2_W-10, BODY_H-10);
  
  // Sys Info
  tft.setTextColor(C_WHITE);
  tft.setTextSize(1);
  tft.setCursor(COL2_X + 15, BODY_Y + 8);
  tft.print("System Info");
  
  // Radar grid
  int cx = COL2_X + COL2_W/2;
  int cy = BODY_Y + 75;
  tft.drawCircle(cx, cy, 25, C_FRAME);
  tft.drawCircle(cx, cy, 15, C_FRAME);
  tft.drawLine(cx-28, cy, cx+28, cy, C_FRAME);
  tft.drawLine(cx, cy-28, cx, cy+28, C_FRAME);
  tft.drawPixel(cx, cy, C_WHITE);
  
  // Telemetry
  tft.setTextColor(C_FRAME);
  tft.setCursor(COL2_X+8, BODY_Y + BODY_H - 40);
  tft.print("CPU:240MHz");
  tft.setCursor(COL2_X+8, BODY_Y + BODY_H - 28);
  tft.print("RAM:OK");
  tft.setCursor(COL2_X+8, BODY_Y + BODY_H - 16);
  tft.print("SPI:40MHz");
}

// Menu Item
void drawMenuItem(int i, bool sel) {
  int yPos = BODY_Y + 8 + (i * 32);
  
  // Clr Row
  tft.fillRect(COL3_X+1, yPos, COL3_W-2, 28, C_BG);
  
  if (sel) {
    // Highlight
    tft.fillRect(COL3_X+1, yPos, COL3_W-2, 28, C_SEL);
    tft.drawBitmap(COL3_X+5, yPos+10, mIcon[i], 8, 8, C_WHITE);
    tft.setTextColor(C_WHITE);
  } else {
    tft.drawBitmap(COL3_X+5, yPos+10, mIcon[i], 8, 8, C_WHITE);
    tft.setTextColor(mColor[i]);
  }
  tft.setTextSize(1);
  tft.setCursor(COL3_X+18, yPos+10);
  tft.print(mLabel[i]);
}

// R-Pane
void drawRightPane() {
  // Stars
  drawStars(COL3_X+5, BODY_Y+5, COL3_W-10, BODY_H-10);
  
  for (int i = 0; i < N_ITEMS; i++)
    drawMenuItem(i, i == curSel);
}

// Footer
void drawFooter() {
  tft.drawLine(0, FTR_Y, 319, FTR_Y, C_WHITE);
  
  // Live Telem
  tft.setTextColor(C_WHITE);
  tft.setTextSize(1);
  tft.setCursor(12, FTR_Y+15);
  tft.print("SD:"); 
  tft.setTextColor(sdOK ? C_UTIL : C_WIFI);
  tft.print(sdOK ? "ONLINE" : "OFFLINE");
  
  // Divider
  tft.drawLine(COL1_W, FTR_Y, COL1_W, 239, C_WHITE);
  
  // Nav
  tft.setTextColor(C_FRAME);
  tft.setCursor(COL1_W+8, FTR_Y+15);
  tft.print("UP/DN: Navig  |  CTR: Activate");
}

// UI scratch
void drawFullUI() {
  tft.fillScreen(C_BG);
  drawHeader();
  drawLeftPane();
  drawMiddlePane();
  drawRightPane();
  drawFooter();
}

// Radar Anim
float radAngle = 0;
unsigned long lastRad = 0;

void updateRadar() {
  unsigned long now = millis();
  if (now - lastRad < 60) return;
  lastRad = now;
  int cx = COL2_X + COL2_W/2;
  int cy = BODY_Y + 75;
  // Erase old
  tft.drawLine(cx, cy, cx+(int)(cos(radAngle)*14), cy+(int)(sin(radAngle)*14), C_BG);
  // Rest grid
  tft.drawLine(cx-28, cy, cx+28, cy, C_FRAME);
  tft.drawLine(cx, cy-28, cx, cy+28, C_FRAME);
  // Draw new
  float a = (now % 3000) / 3000.0 * 2 * PI;
  tft.drawLine(cx, cy, cx+(int)(cos(a)*14), cy+(int)(sin(a)*14), C_BLE);
  tft.drawPixel(cx, cy, C_WHITE);
  radAngle = a;
}

void setupPeripherals() {
  spiSD.begin(SD_SCK, SD_MISO, SD_MOSI, -1);
  pinMode(TFT_CS, OUTPUT); digitalWrite(TFT_CS, HIGH);
  pinMode(SD_CS, OUTPUT); digitalWrite(SD_CS, HIGH);
  if (SD.begin(SD_CS, spiSD, 1000000)) sdOK = true;
  else { delay(500); if (SD.begin(SD_CS, spiSD, 1000000)) sdOK = true; }
  gpsSerial.begin(9600);
  uart32u.begin(9600, SERIAL_8N1, UART32U_RX, UART32U_TX);   // 9600 to match slave_32u
  esp8266.begin(9600, SERIAL_8N1, ESP8266_RX, ESP8266_TX);    // 9600 to match slave_8266
}

void setup() {
  Serial.begin(115200); delay(1000);
  pinMode(JOY_UP, INPUT_PULLUP);
  pinMode(JOY_DOWN, INPUT_PULLUP);
  pinMode(JOY_LEFT, INPUT_PULLUP);
  pinMode(JOY_RIGHT, INPUT_PULLUP);
  pinMode(JOY_CENTER, INPUT_PULLUP);
  
  pinMode(TFT_RST, OUTPUT);
  digitalWrite(TFT_RST, HIGH); delay(100);  // Rst High
  digitalWrite(TFT_RST, LOW);  delay(150);  // Rst Low
  digitalWrite(TFT_RST, HIGH); delay(300);  // Wait
  
  tftSPI.begin(TFT_SCK, -1, TFT_MOSI, -1);
  
  // Init TFT
  #if USE_ILI9341
    tft.begin(40000000); // Initialize ILI9341 SPI at 40MHz
  #else
    tft.init(240, 320);  // Initialize ST7789 SPI
    tft.setSPISpeed(40000000);
  #endif
  
  tft.setRotation(1);  // Landscape
  
  #if INVERT_COLORS
    tft.invertDisplay(true);
  #else
    tft.invertDisplay(false);
  #endif
  
  // Boot SCR
  Serial.println("Initializing TFT...");
  tft.fillScreen(C_BG);
  tft.setTextColor(C_WHITE); tft.setTextSize(1);
  tft.setCursor(20, 100); tft.print("> SLAYER CORE INITIALIZATION...");
  Serial.println("> SLAYER CORE INITIALIZATION...");
  
  setupPeripherals();
  
  tft.setCursor(20, 115);
  tft.setTextColor(sdOK ? C_UTIL : C_WIFI);
  tft.print(sdOK ? "> SD: ONLINE" : "> SD: OFFLINE");
  Serial.println(sdOK ? "> SD: ONLINE" : "> SD: OFFLINE");
  delay(500);
  
  Serial.println("Starting UI...");
  drawFullUI();
}

void processBackgroundTasks() {
  while (gpsSerial.available()) gps.encode(gpsSerial.read());
  while (uart32u.available()) uart32u.read();
  while (esp8266.available()) esp8266.read();
}

bool pingModule(HardwareSerial& serial) {
  // Clr RX
  while(serial.available()) serial.read();
  
  // Ping
  serial.println("ping");
  
  // Wait RX
  unsigned long t = millis();
  while(millis() - t < 500) {
    if(serial.available()) {
      // Clr RX
      while(serial.available()) serial.read();
      return true;
    }
    delay(5);
  }
  return false;
}

// Submenu
void runSubMenu() {
  tft.fillScreen(C_BG);
  drawCorners(0, 0, 320, 240, 12, mColor[curSel]);
  
  tft.drawBitmap(14, 8, ico_batt, 16, 10, C_WHITE);
  tft.setTextColor(C_WHITE); tft.setTextSize(1);
  tft.setCursor(36, 10); tft.print("Slayer > ");
  tft.setTextColor(mColor[curSel]); tft.print(mLabel[curSel]);
  tft.drawLine(0, HDR_H-1, 319, HDR_H-1, mColor[curSel]);
  
  tft.drawRect(15, 40, 290, 160, mColor[curSel]);
  drawStars(20, 45, 280, 150);
  
  tft.setTextColor(mColor[curSel]); tft.setCursor(25, 55);
  
  if (curSel == 3) {
    tft.print("=== HW DIAGNOSTICS ===");
    tft.setTextColor(C_WHITE);
    tft.setCursor(25, 75); tft.printf("SD Card .... %s", sdOK?"ONLINE":"OFFLINE");
    tft.setCursor(25, 90); tft.printf("GPS Sats ... %d", gps.satellites.value());
    // Ping UART
    bool u32 = pingModule(uart32u);
    bool u82 = pingModule(esp8266);
    
    tft.setCursor(25, 105); tft.printf("UART-32U ... %s", u32 ? "ACTIVE" : "NO RESP");
    tft.setCursor(25, 120); tft.printf("UART-8266 .. %s", u82 ? "ACTIVE" : "NO RESP");
    tft.setCursor(25, 135); tft.print("TFT ........ ILI9341 OK");
    tft.setCursor(25, 150); tft.printf("Heap ....... %d B", ESP.getFreeHeap());
  } else if (curSel == 4) {
    tft.print("=== CONFIG ===");
    tft.setTextColor(C_WHITE);
    tft.setCursor(25, 75); tft.print("Board: ESP32-S3 WROOM-1");
    tft.setCursor(25, 90); tft.print("Display: 240x320 2.4\" TFT");
    tft.setCursor(25, 105); tft.print("SPI: 40MHz Hardware SPI");
  } else {
    tft.print("=== MODULE STANDBY ===");
    tft.setTextColor(C_FRAME);
    tft.setCursor(25, 80); tft.print("Awaiting activation command...");
  }
  
  tft.setTextColor(C_FRAME);
  tft.setCursor(25, 210); tft.print("> CENTER to return");
  
  delay(200);
  while(!digitalRead(JOY_CENTER)) { processBackgroundTasks(); delay(10); }
  delay(50);
  while(digitalRead(JOY_CENTER)) { processBackgroundTasks(); delay(10); }
  delay(50);
  while(!digitalRead(JOY_CENTER)) { processBackgroundTasks(); delay(10); }
  drawFullUI();
}

void loop() {
  processBackgroundTasks();
  updateRadar();
  
  bool cu = !digitalRead(JOY_UP);
  bool cd = !digitalRead(JOY_DOWN);
  bool cc = !digitalRead(JOY_CENTER);
  
  if (cu && !joyU) {
    int old = curSel;
    curSel = (curSel - 1 + N_ITEMS) % N_ITEMS;
    drawMenuItem(old, false);
    drawMenuItem(curSel, true);
  }
  joyU = cu;
  
  if (cd && !joyD) {
    int old = curSel;
    curSel = (curSel + 1) % N_ITEMS;
    drawMenuItem(old, false);
    drawMenuItem(curSel, true);
  }
  joyD = cd;
  
  if (cc && !joyC) runSubMenu();
  joyC = cc;
  
  delay(10);
}

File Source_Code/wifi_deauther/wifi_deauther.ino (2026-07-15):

// ESP8266 WiFi Attack Tool | UART to Master: RX=GPIO3, TX=GPIO1

#include <SoftwareSerial.h>
#include "deauth_utils.h"
DeauthEngine engine;

// S3 Conn
SoftwareSerial MasterSerial(5, 4); // RX=D1(GPIO5), TX=D2(GPIO4)

// Buffers
String masterRxBuffer = "";
String usbRxBuffer = "";

// LED
#define LED_PIN 2

// Stat Tmr
unsigned long lastStats = 0;
const unsigned long STATS_INTERVAL = 1000;

// Setup

void setup() {
  Serial.begin(115200); // FAST baud for debug to prevent blocking
  delay(500);
  MasterSerial.begin(9600); // Connection to S3 Master

  // Max TX
  WiFi.setOutputPower(20.5);

  pinMode(LED_PIN, OUTPUT);
  digitalWrite(LED_PIN, HIGH);  // LED Off

  Serial.println();
  Serial.println(F("========================================"));
  Serial.println(F("  ESP8266 WiFi Attack Tool v1.0"));
  Serial.println(F("  NodeMCU v3 | Custom Implementation"));
  Serial.println(F("========================================"));
  Serial.println();

  printMenu();
}

// Main Loop

void loop() {
  // RX from Master
  while (MasterSerial.available()) {
    char c = (char)MasterSerial.read();
    if (c == '\n') {
      masterRxBuffer.trim();
      if (masterRxBuffer.length() > 0) {
        if (masterRxBuffer == "ping") {
          MasterSerial.println("pong");
        } else {
          handleCommand(masterRxBuffer);
        }
      }
      masterRxBuffer = "";
    } else if (c != '\r') {
      masterRxBuffer += c;
      if (masterRxBuffer.length() > 200) masterRxBuffer = ""; // Clr
    }
  }

  // RX from USB
  while (Serial.available()) {
    char c = (char)Serial.read();
    if (c == '\n') {
      usbRxBuffer.trim();
      if (usbRxBuffer.length() > 0) {
        handleCommand(usbRxBuffer);
      }
      usbRxBuffer = "";
    } else if (c != '\r') {
      usbRxBuffer += c;
      if (usbRxBuffer.length() > 200) usbRxBuffer = "";
    }
  }

  // Attack engine
  engine.update();

  // LED status
  if (engine.isActive()) {
    // LED blink
    digitalWrite(LED_PIN, (millis() / 200) % 2 == 0 ? LOW : HIGH);
  } else {
    digitalWrite(LED_PIN, HIGH);  // LED Off
  }

  // Stats
  if (engine.isActive() && millis() - lastStats >= STATS_INTERVAL) {
    lastStats = millis();
    Serial.printf("STATUS:%s:pkts=%lu:bursts=%lu\n",
                  engine.getModeName(),
                  engine.getPacketsSent(),
                  engine.getBurstCount());
    MasterSerial.printf("STATUS:WIFI:%lu:%lu\n",
                  engine.getPacketsSent(),
                  engine.getBurstCount());
  }
}

// Command Handler

void handleCommand(String line) {

  if (line.startsWith("CMD:")) {
    handleProtocolCommand(line.substring(4));
    return;
  }


  if (line == "scan") {
    doScan();
  }
  else if (line.startsWith("deauth ")) {
    int idx = line.substring(7).toInt() - 1;
    if (idx >= 0 && idx < engine.getNetworkCount()) {
      WiFiTarget t = engine.getTarget(idx);
      engine.startDeauth(t.bssid, t.channel);
    } else {
      Serial.println(F("[!] Invalid index. Run 'scan' first."));
    }
  }
  else if (line.startsWith("beacon ")) {
    String name = line.substring(7);
    engine.startBeaconFlood(name.c_str(), 6);  // Default ch 6
  }
  else if (line == "stop") {
    engine.stop();
  }
  else if (line == "status") {
    printStatus();
  }
  else if (line == "?") {
    printMenu();
  }
  else {
    Serial.printf("[?] Unknown: '%s' — type '?' for help\n", line.c_str());
    MasterSerial.printf("[?] Unknown: '%s'\n", line.c_str());
  }
}

// Protocol Handler

void handleProtocolCommand(String cmd) {
  if (cmd == "SCAN") {
    doScan();
  }
  else if (cmd.startsWith("DEAUTH:")) {
    // Fmt: DEAUTH:MAC:ch
    // Parse
    String params = cmd.substring(7);  // After "DEAUTH:"

    uint8_t bssid[6];
    uint8_t channel = 0;

    // Parse MAC
    int colonCount = 0;
    int lastColon = -1;
    for (int i = 0; i < params.length(); i++) {
      if (params.charAt(i) == ':') {
        colonCount++;
        if (colonCount == 6) {
          // Split
          String bssidStr = params.substring(0, i);
          channel = params.substring(i + 1).toInt();
          sscanf(bssidStr.c_str(), "%hhx:%hhx:%hhx:%hhx:%hhx:%hhx",
                 &bssid[0], &bssid[1], &bssid[2],
                 &bssid[3], &bssid[4], &bssid[5]);
          break;
        }
      }
    }

    if (channel > 0) {
      engine.startDeauth(bssid, channel);
      Serial.println("DEAUTH:ACTIVE");
      MasterSerial.println("DEAUTH:ACTIVE");
    } else {
      Serial.println("DEAUTH:ERROR:invalid params");
      MasterSerial.println("DEAUTH:ERROR:invalid params");
    }
  }
  else if (cmd.startsWith("BEACON:")) {
    // Fmt: BEACON:SSID:ch
    String params = cmd.substring(7);
    int lastColon = params.lastIndexOf(':');
    if (lastColon > 0) {
      String ssid = params.substring(0, lastColon);
      uint8_t ch = params.substring(lastColon + 1).toInt();
      engine.startBeaconFlood(ssid.c_str(), ch);
      Serial.println("BEACON:ACTIVE");
      MasterSerial.println("BEACON:ACTIVE");
    }
  }
  else if (cmd == "STOP") {
    engine.stop();
    Serial.println("STOP:OK");
    MasterSerial.println("STOP:OK");
  }
  else if (cmd == "STATUS") {
    printStatus();
  }
}

// WiFi Scan

void doScan() {
  Serial.println(F("\n[SCAN] Scanning WiFi networks..."));
  MasterSerial.println(F("SCANNING..."));
  int n = engine.scanNetworks();

  if (n == 0) {
    Serial.println(F("SCAN:0"));
    MasterSerial.println(F("SCAN:0"));
    return;
  }

  Serial.printf("SCAN:%d networks found\n", n);
  MasterSerial.printf("SCAN:%d networks found\n", n);
  Serial.println(F("─────────────────────────────────────────────"));

  for (int i = 0; i < n; i++) {
    WiFiTarget t = engine.getTarget(i);
    Serial.printf(" %2d) %-24s  BSSID:%s  Ch:%2d  %ddBm\n",
                  i + 1,
                  t.ssid.c_str(),
                  t.bssid_str.c_str(),
                  t.channel,
                  t.rssi);
    // TX Data
    MasterSerial.printf("NET:%d:%s:%d:%s:%d\n", 
                  i, t.ssid.c_str(), t.rssi, t.bssid_str.c_str(), t.channel);
  }
  MasterSerial.println(F("SCAN_COMPLETE"));
  Serial.println(F("─────────────────────────────────────────────"));
  Serial.println(F("Type 'deauth <number>' to attack a network"));
  Serial.println();
}

// Status & Menu

void printStatus() {
  Serial.printf("STATUS:%s:pkts=%lu:bursts=%lu\n",
                engine.getModeName(),
                engine.getPacketsSent(),
                engine.getBurstCount());
  MasterSerial.printf("STATUS:%s:pkts=%lu:bursts=%lu\n",
                engine.getModeName(),
                engine.getPacketsSent(),
                engine.getBurstCount());
}
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
